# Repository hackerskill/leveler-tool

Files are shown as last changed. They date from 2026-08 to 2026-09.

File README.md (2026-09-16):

# leveler-tool
&#x09;

### A interactive leveler tool based on rp 2040 with acceleration sensor and led matrix.
---
Used to measure angle of displacement for a horizontal or a vertical surface, based on RP2040 with acceleration sensor and led matrix. Modules plug in into the custom PCB, allowing for measuring angle of displacement for a horizontal or a vertical surface.

## Features
- XIAO RP2040 acts as the main microcontroller
- Real time tilt measurement using an ADXL345
- MAX7219 LED matrix for visual feedback
- Active buzzer for audio feedback
- Cherry MX switch for user input
- USB-C connectivity through the XIAO RP2040 for Power
- Compact custom PCB

---

# Schematics-
leveler-tool-schematics

# PCB-
leveler-tool

## How It Works

1. The ADXL345 continuously measures acceleration along its three axes.

2. The RP2040 processes these measurements and converts them to angle. The resulting angle is used to determine which leds should be turned on using the LED matrix.

3. The Buzzer turns on when the device is exactly parallel to the surface.

4. The Cherry MX switch is used for user interaction such as changing modes or temporary turning off.

# BOM-
| Component Name | Description | Quantity |
| :--- | :--- | :---: |
| **Seeed Studio Xiao RP2040** | Devboard for RP2040 Chipset | 1 |
| **MAX7219** | 8x8 LED Display Matrix | 1 |
| **ADXL345** | 3-Axis Digital Accelerometer Module | 1 |
| **Active Buzzer** | 3V3 Active Buzzer | 1 |
| **Custom PCB** | Custom PCB | 1 |

---

**Made by hackerskill**

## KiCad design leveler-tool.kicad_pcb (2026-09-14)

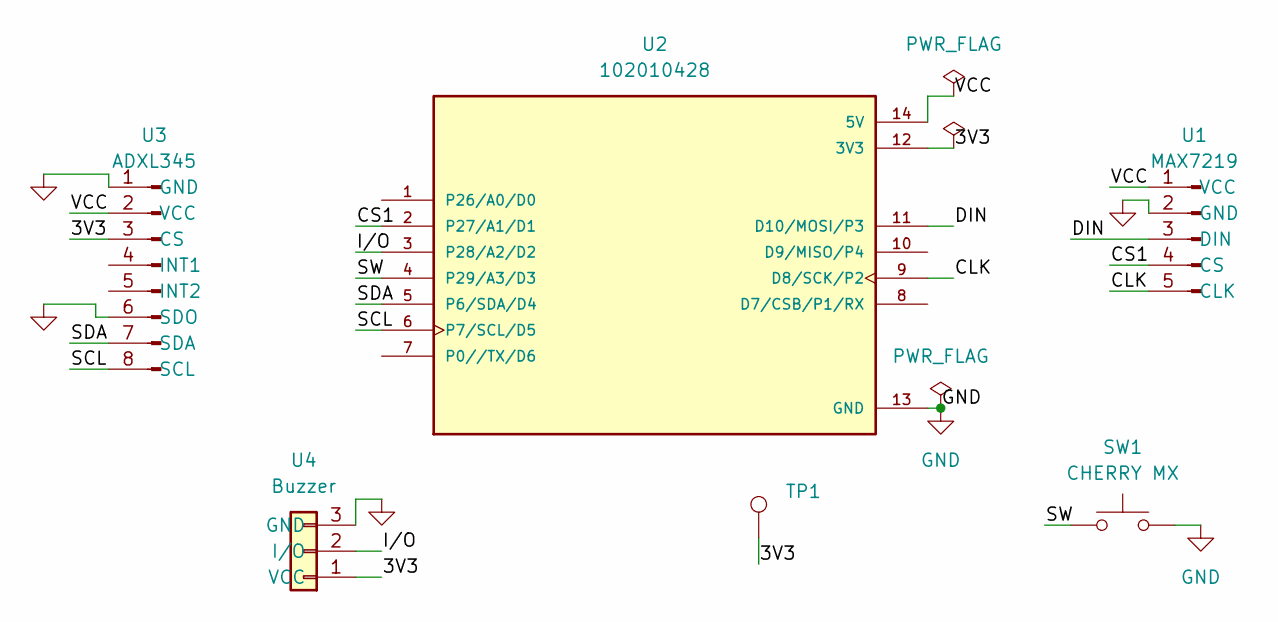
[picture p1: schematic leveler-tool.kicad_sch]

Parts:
SW1: CHERRY MX; SW_Cherry_MX_1.00u_PCB
TP1: TestPoint; PinSocket_1x01_P2.54mm_Vertical
U1: MAX7219; PinSocket_1x05_P2.54mm_Vertical
U2: 102010428; XIAO-RP2040-DIP; PARTREV 1.3
U3: ADXL345; PinSocket_1x08_P2.54mm_Vertical
U4: Buzzer; PinSocket_1x03_P2.54mm_Vertical

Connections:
/3V3: TP1.1 (1_1), U2.12 (3V3), U3.3 (CS), U4.1 (VCC)
/CLK: U1.5 (CLK), U2.9 (D8/SCK/P2)
/CS1: U1.4 (CS), U2.2 (P27/A1/D1)
/DIN: U1.3 (DIN), U2.11 (D10/MOSI/P3)
/I/O: U2.3 (P28/A2/D2), U4.2 (I/O)
/SCL: U2.6 (P7/SCL/D5), U3.8 (SCL)
/SDA: U2.5 (P6/SDA/D4), U3.7 (SDA)
/SW: SW1.1, U2.4 (P29/A3/D3)
/VCC: U1.1 (VCC), U2.14 (5V), U3.2 (VCC)
GND: SW1.2, U1.2 (GND), U2.13 (GND), U3.1 (GND), U3.6 (SDO), U4.3 (GND)

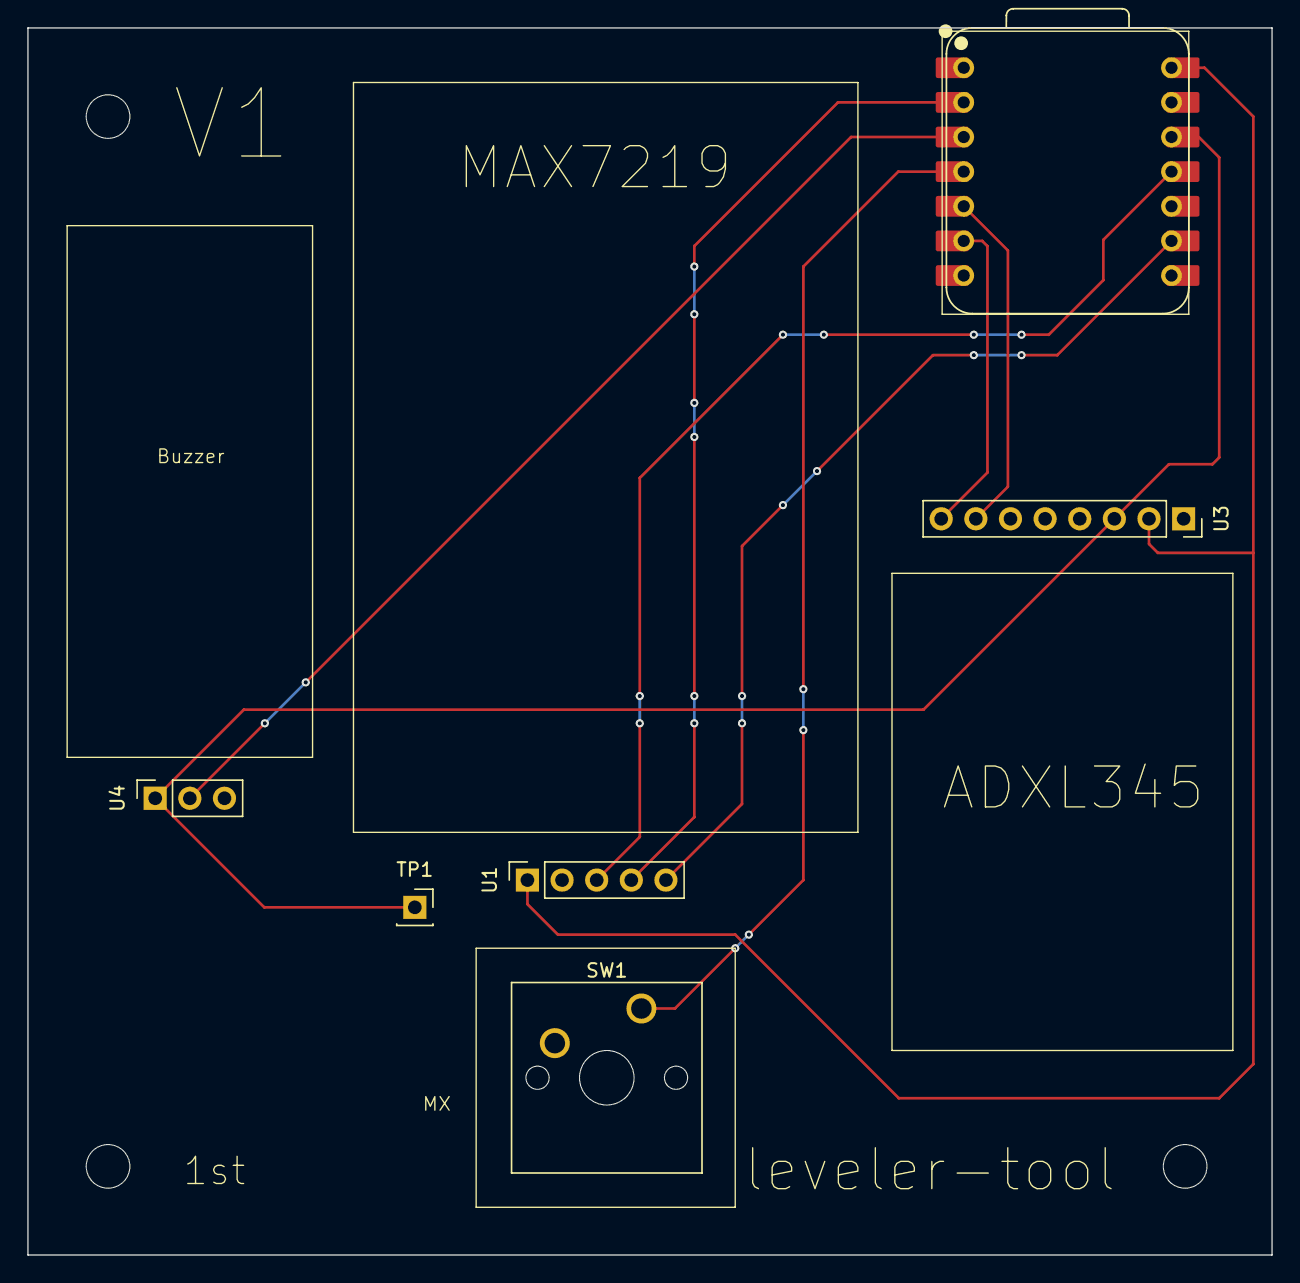
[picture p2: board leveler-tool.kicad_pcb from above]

Board: 2 copper layers, 91.2 x 90.0 mm, 6 parts (0 on the bottom side), 10 nets.

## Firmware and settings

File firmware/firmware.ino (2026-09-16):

#include <Wire.h>
#include <Adafruit_Sensor.h>
#include <Adafruit_ADXL345_U.h>
#include <MD_MAX72xx.h>

#define HARDWARE_TYPE MD_MAX72XX::FC16_HW // If data looks upside-down, backwards or scrambled, change this to GENERIC_HW, ICSTATION_HW or PAROLA_HW
#define MAX_DEVICES 1

const int CS1 = 27; // D1
const int IO = 28;  // D2
const int SW = 29;  // D3

const byte LEVEL_HEX[8]={      //Hex pattern when PCB is direclty parallel to surface
  0x18, // ◯◯◯●●◯◯◯
  0x18, // ◯◯◯●●◯◯◯
  0x18, // ◯◯◯●●◯◯◯
  0xFF, // ●●●●●●●●
  0xFF, // ●●●●●●●●
  0x18, // ◯◯◯●●◯◯◯
  0x18, // ◯◯◯●●◯◯◯
  0x18  // ◯◯◯●●◯◯◯
};

MD_MAX72XX mx = MD_MAX72XX(HARDWARE_TYPE, CS1, MAX_DEVICES);

Adafruit_ADXL345_Unified accel = Adafruit_ADXL345_Unified(12345);

const float LEVEL_TOLERANCE = 0.40; // Adjust based on vibration levels
const float MAX_VISIBLE_ANGLE = 45.0;

void displayParallel() {
  if (digitalRead(SW) == LOW) {
    digitalWrite(IO, HIGH); 
  } 
  else {
    digitalWrite(IO, LOW);  // Keep it muted if the switch is open (HIGH)
  }
  for (uint8_t row = 0; row < 8; row++) {
    mx.setRow(0, row, LEVEL_HEX[row]);
  }
}

void setup() {
  Wire.begin();
  Serial.begin(115200);

  pinMode(CS1, OUTPUT);
  pinMode(IO, OUTPUT);
  pinMode(SW, INPUT_PULLUP);

  Serial.println("Initialising");

  mx.begin();
  mx.control(MD_MAX72XX::INTENSITY, 5); // Brightness (0-15)
  mx.clear();

  accel.begin();
  accel.setRange(ADXL345_RANGE_2_G);
  
  Serial.println("Starting");
}

void loop() {
  sensors_event_t event; 
  accel.getEvent(&event);

  float xForce = event.acceleration.x;
  float yForce = event.acceleration.y;
  float zForce = event.acceleration.z;

  float angle = atan2(yForce, zForce) * 180.0 / M_PI; // Converted to angle in degrees

  mx.clear();

  if (angle >= -LEVEL_TOLERANCE && angle <= LEVEL_TOLERANCE) {
    displayParallel();
    digitalWrite(IO, HIGH);
  }
  else {
    digitalWrite(IO, LOW);
    float constrainedAngle = constrain(angle, -MAX_VISIBLE_ANGLE, MAX_VISIBLE_ANGLE);
    int centerRow = map(constrainedAngle, -MAX_VISIBLE_ANGLE, MAX_VISIBLE_ANGLE, 0, 7);

    for (int col = 0; col < 8; col++) {
      int targetRow = centerRow + (col - 4); 

      if (targetRow >= 0 && targetRow < 8) {
        mx.setPoint(targetRow, col, true); 
      }
    }
  }

  delay(100);
}

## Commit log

2026-08-06 Schematics work
    Started the project and almost completed the schematics
    [runtime-hackpad.kicad_pcb, runtime-hackpad.kicad_sch]
2026-08-07 Schematics work completed
    [runtime-hackpad.kicad_pcb, runtime-hackpad.kicad_sch]
2026-08-08 PCB work
    [runtime-hackpad.kicad_pcb]
2026-08-10 pcb work done
    [runtime-hackpad.kicad_pcb]
2026-09-05 header correction
    [leveler-tool.kicad_pcb, leveler-tool.kicad_sch]
2026-09-14 pcb done
    [leveler-tool.kicad_pcb]
2026-09-16 Buzzer and switch implemented
    [firmware.ino]
